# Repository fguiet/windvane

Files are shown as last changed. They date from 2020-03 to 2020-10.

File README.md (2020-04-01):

# Solar powered, waterproof windvane

## Foreword

Following my first project ie a [solar powered waterproof anemoter](https://github.com/fguiet/anemometer), let me introduce you : the solar powered waterproof windvane.
Mostly based on the same form factor, I only had to re-designed the top part with Fusion 360.

## How it works ?

There are eight resistors in the wind vane, and as the magnet rotates, different reed switches will open and close and thus switch their corresponding resistor in and out of the circuit.

Schematic reedwitches and resistors

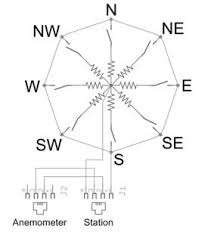
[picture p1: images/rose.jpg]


Implementation reedswitches and resistors

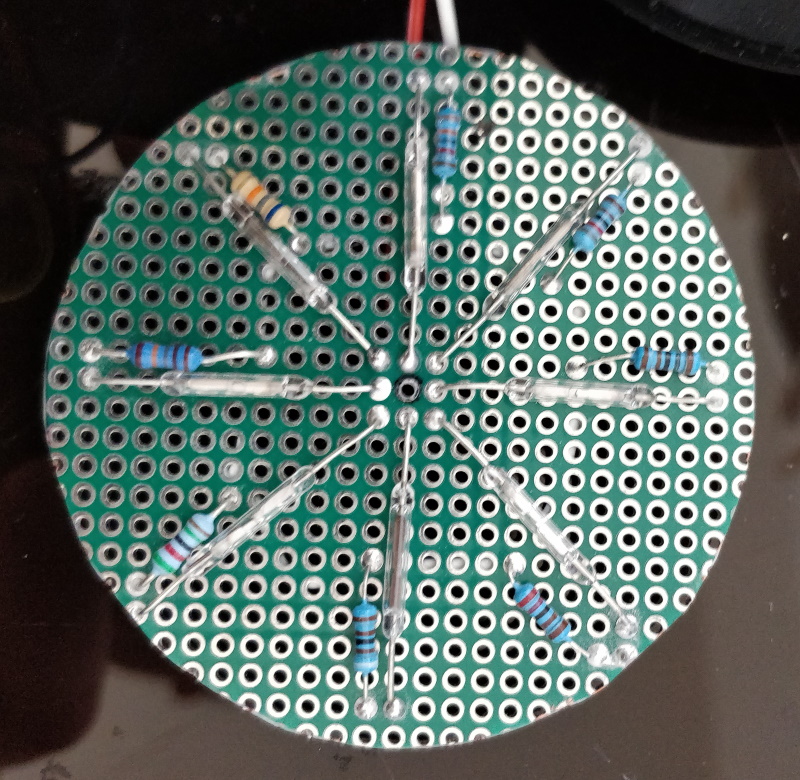
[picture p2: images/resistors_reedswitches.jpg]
Reedswitch


Voltage divider (R1 is 10kOhm is this project and R2 will vary regarding how reed switches are open or close)

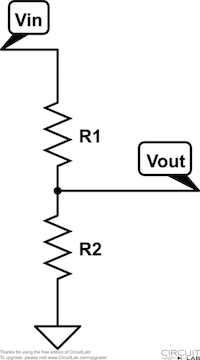
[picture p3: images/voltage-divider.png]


## Specifications

Electronic spare parts needed :

* 3.7v Lithium battery (650 mAh)
* [Lithium battery charger module TP4056](https://www.aliexpress.com/item/32797834680.html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,searchweb201602_,searchweb201603_)
* [ESP32 DevKit)](https://www.aliexpress.com/item/32818515531.html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,searchweb201602_,searchweb201603_)
* Home made voltage divider with 2 resitors 33KOhm and 7.5kOhm
* [Solar panel](https://www.aliexpress.com/item/32327321902.html?spm=a2g0s.9042311.0.0.27424c4dXw694V)
* [XH2.54 connectors](https://www.aliexpress.com/item/32751262161.html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,searchweb201602_,searchweb201603_)
* [30 AWG (0.08mm) silicon wire](https://www.aliexpress.com/item/1000006501735.html?spm=a2g0s.9042311.0.0.27424c4d4oyuHy)
* 3.7v Lithium battery (1200 mAh)
* [Bearing 608ZZ](https://www.aliexpress.com/wholesale?catId=0&initiative_id=SB_20200219052438&SearchText=bearing+608)
* [4 neodymium magnets (8mm)](https://www.aliexpress.com/item/32959402237.html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,searchweb201602_,searchweb201603_)
* Some resistors
* Some nuts and bolts

## Wiring

Quite easy : 

* Wire positive and negative 3.7v battery to ESP32 DevKit (Careful connect to 5v pin, not 3.3v !!), Voltage divider (the one that will measure the battery voltage),  TP4056 
* Wire the voltage divider that will measure the wind direction to 3.3v pin (that way we have a constant voltage)
* GPIO34 to output of voltage divider (measure wind direction)
* GPIO35 to ouput of voltage divider (measure battery voltage)

## 3D Models

All 3D models can be found on my [Thingiverse for free](https://www.thingiverse.com/thing:4252764) or in the model3d folder of this project

I included a mount system that fits on H pole like this one : 

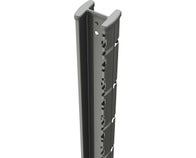
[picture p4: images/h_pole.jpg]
Sweet


If needed, I can provide the 3d model solar panel holder

## In real life

* In place

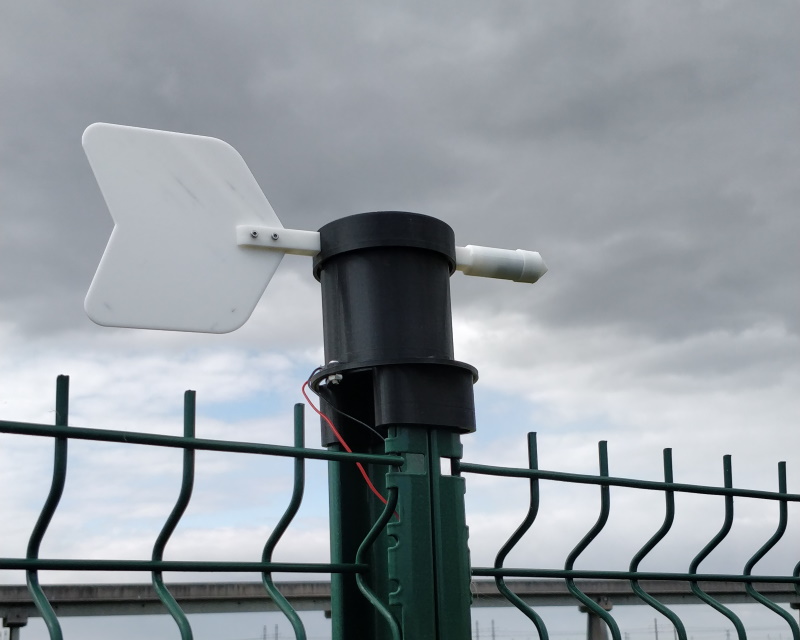
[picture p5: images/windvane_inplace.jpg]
In place


* Inside the beast (we can the custom voltage divider)

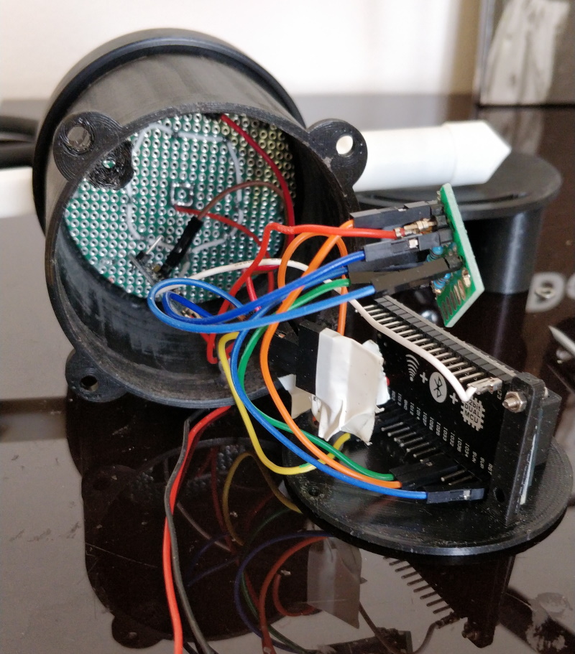
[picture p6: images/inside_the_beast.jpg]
Inside the beast


* Fusion 360 design

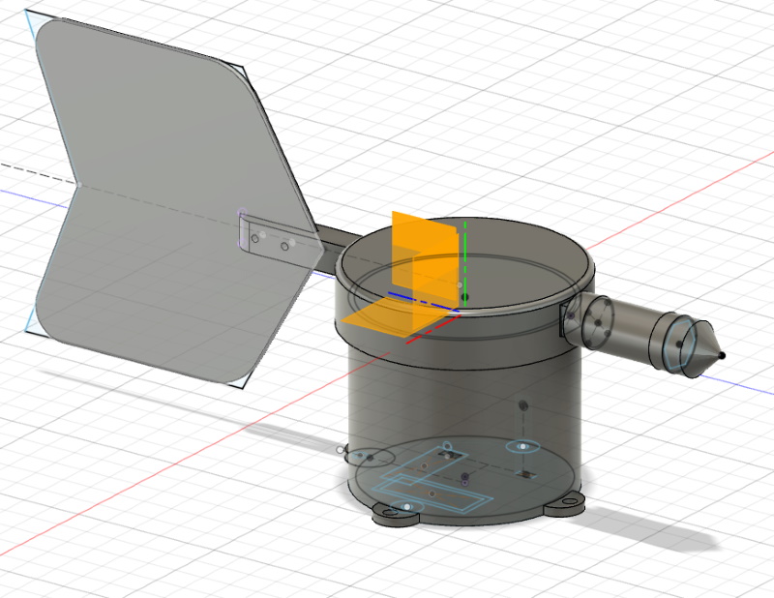
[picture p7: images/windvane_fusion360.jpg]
Fusion 360


* Tampered ESP32 DevKit (I replaced the AMS1117 LDO 1v dropout by HT7333 only 250mA but low dropout)

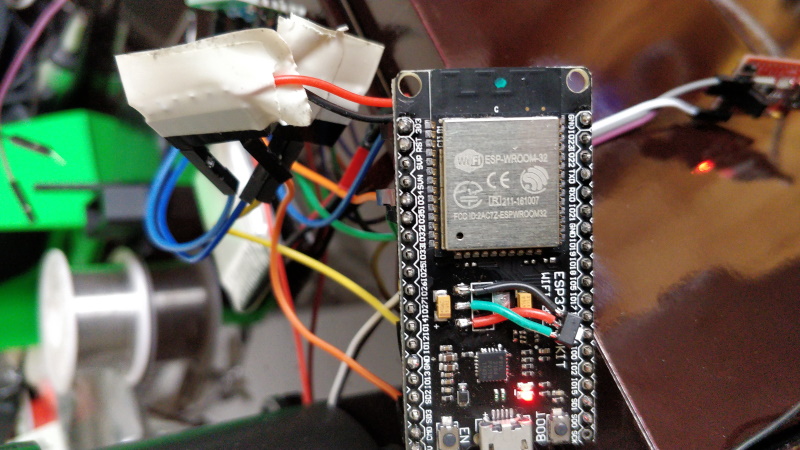
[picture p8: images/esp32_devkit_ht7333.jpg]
Tampered ESP32


* Top view (we can see the bearing)

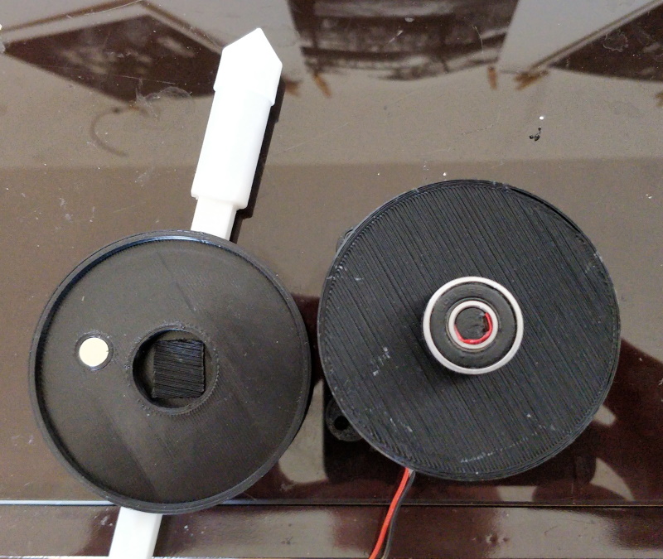
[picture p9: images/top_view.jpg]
Top view


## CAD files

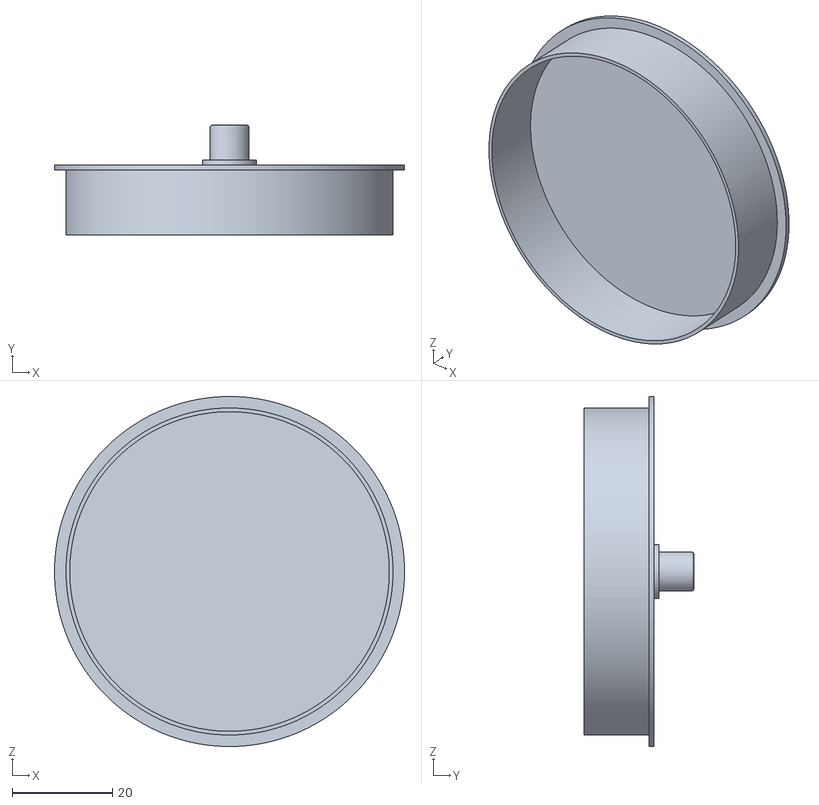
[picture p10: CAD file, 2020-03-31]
model3d/top.stl
70.0 x 22.0 x 70.0

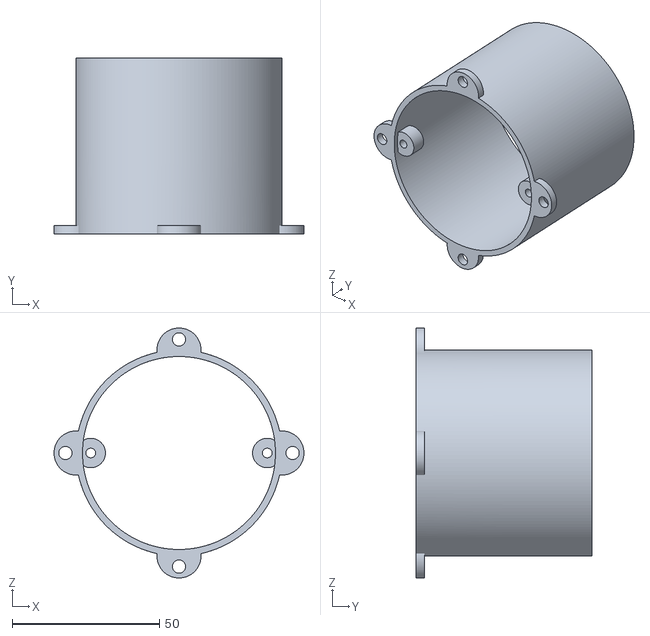
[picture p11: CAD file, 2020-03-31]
model3d/body.stl
85.0 x 60.0 x 85.0

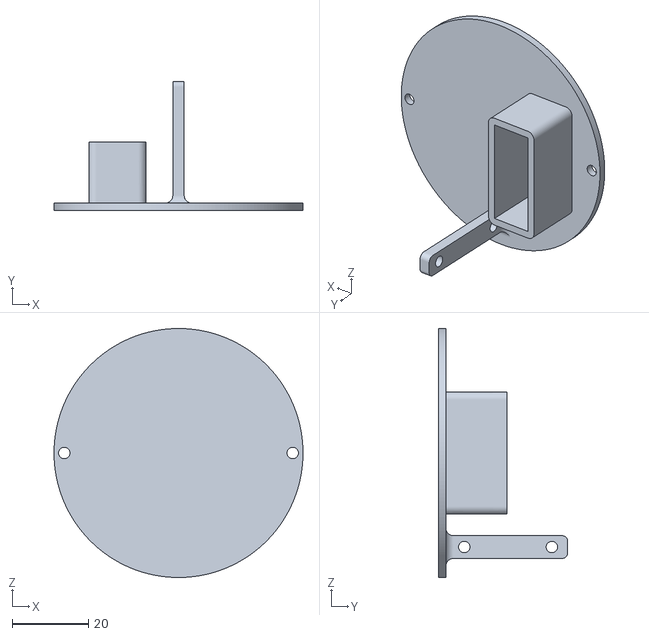
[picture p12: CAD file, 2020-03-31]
model3d/Bottom_ESP32devkit.stl
65.4 x 34.0 x 65.4

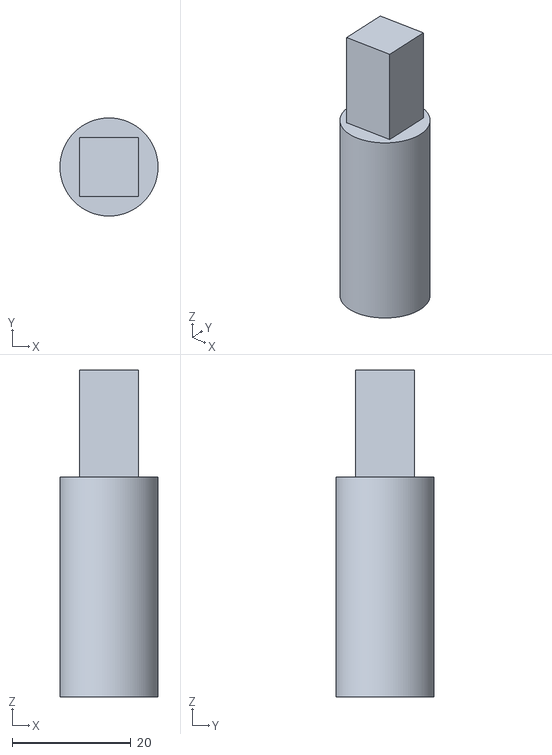
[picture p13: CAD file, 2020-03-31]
model3d/begintail.stl
16.5 x 16.5 x 55.0

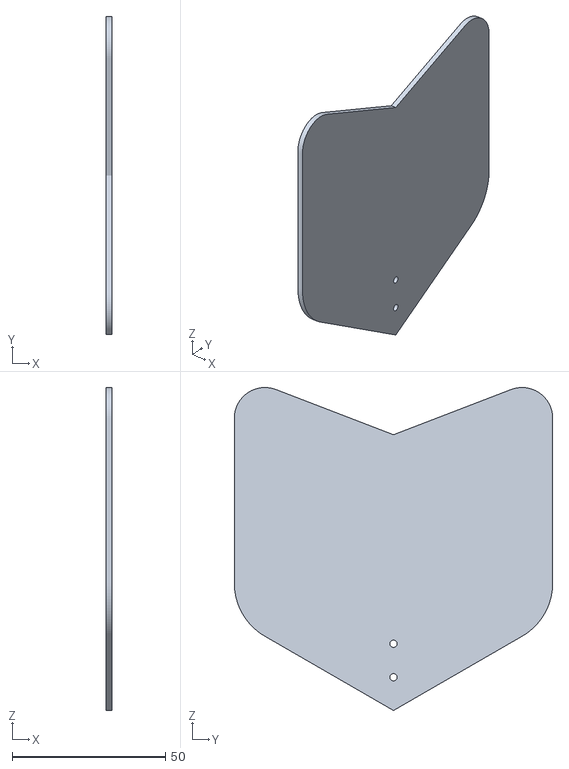
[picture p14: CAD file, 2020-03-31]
model3d/endtail.stl
2.00 x 103.9 x 105.4

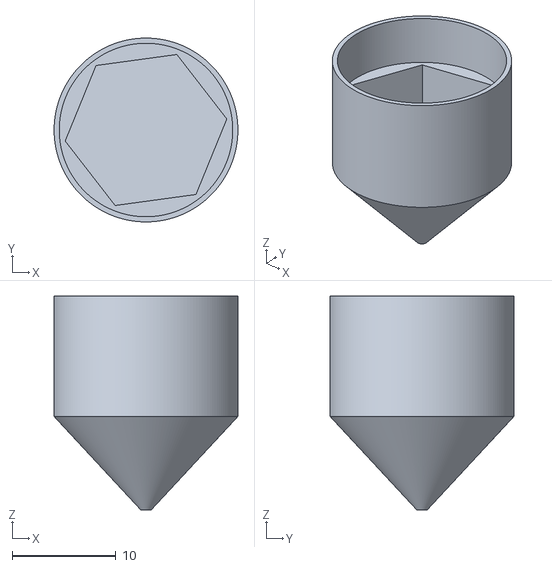
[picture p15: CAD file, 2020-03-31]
model3d/noze.stl
17.7 x 17.7 x 20.6

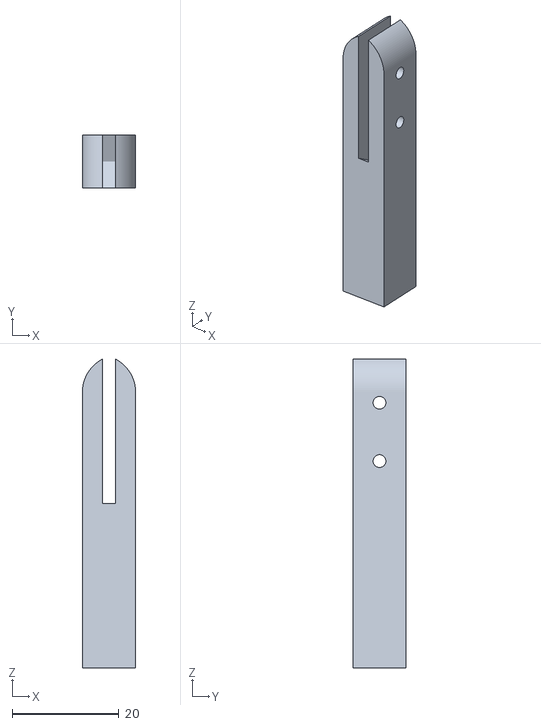
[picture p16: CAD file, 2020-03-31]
model3d/tail.stl
10.0 x 10.0 x 58.0

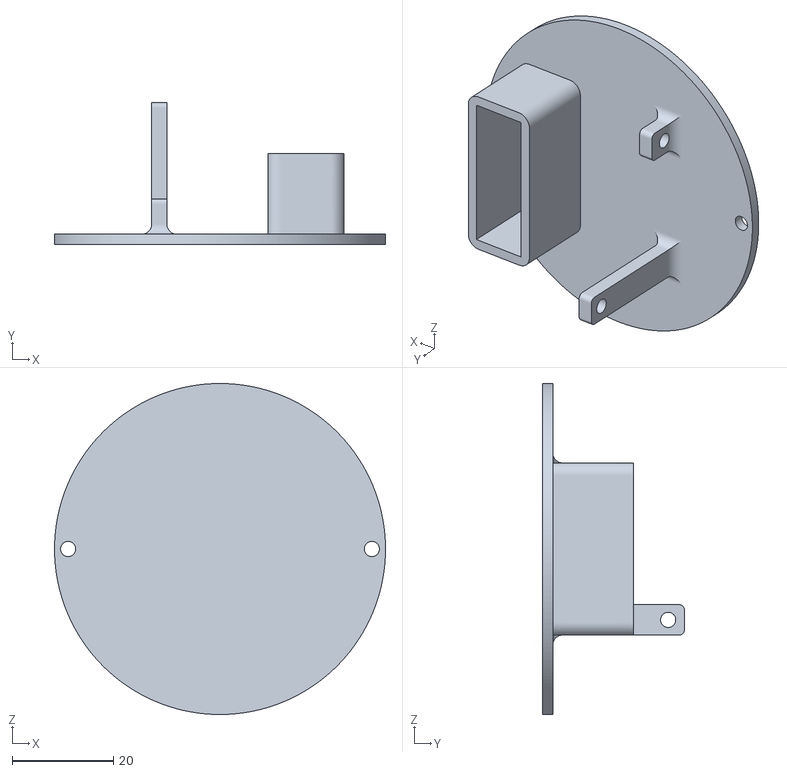
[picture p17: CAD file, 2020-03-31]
model3d/Bottom_WemosD1.stl
65.4 x 28.0 x 65.4

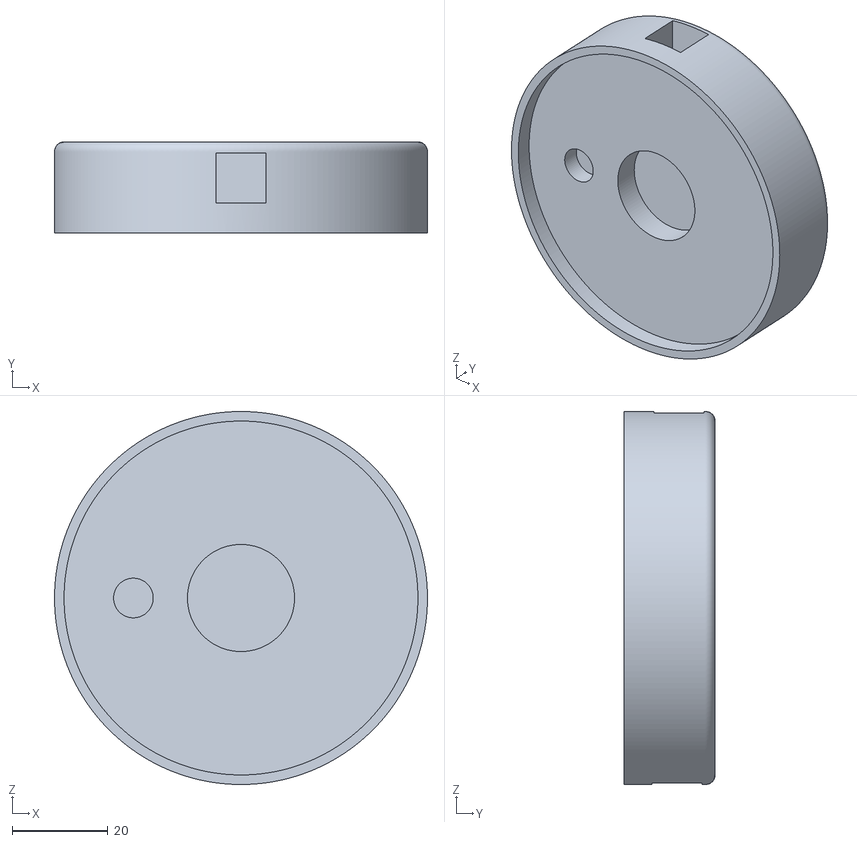
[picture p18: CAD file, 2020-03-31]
model3d/roof.stl
78.0 x 19.1 x 78.0

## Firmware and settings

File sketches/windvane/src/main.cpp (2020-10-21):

/* 
Windvane

   Author :             F. Guiet 
   Creation           : 20200324
   Last modification  : 
  
  Version            : 1.0
  History            : 1.0 - First version
                       1.1 - Replaced AMS117 LDO regulator to HT7333 LDO (1V dropout of AMS117 was too much when powered ESP32 via 5v pin with 3.7v lithium battery) 
                             => the 3.3v pin displayed 2.8v ... when battery was 3.9v :( with HT7333 it's much better...but wareful it can deliver only 250mA max) 
                       1.2 - 2020.04.01 - Read voltage correction. 
                       1.3 - 2020.10.17 - Take "Unknown value into account...otherwise it could drain the battery when reedwitch are ko  
                       1.4 - 2020.10.17 - Switch to PlatformIO, replace ESP32 Dev Kit          
                       
References :   

ESP32 Dev kit : https://randomnerdtutorials.com/getting-started-with-esp32/

Deep sleep mode consumption (ESP32 Devkit) : 7.3mA 
Wake up mode (ESP32 Devkit)                : 63mA

*/
#include <Arduino.h>
#include <ArduinoJson.h>
//Light Mqtt library
#include <PubSubClient.h>
//Wifi library
#include <WiFi.h>

#include "soc/soc.h"           // Disable brownour problems
#include "soc/rtc_cntl_reg.h"  // Disable brownour problems

#define MQTT_SERVER "192.168.1.25"
// WiFi settings
const char* ssid = "DUMBLEDORE";
const char* password = "frederic";

#define MQTT_CLIENT_ID "WindvaneSensor"
#define MAX_RETRY 500

WiFiClient espClient;
PubSubClient client(espClient);

#define DEBUG 0
#define FIRMWARE_VERSION "1.4"

int counter = 0;
int samples = 9;
unsigned long last_millis = 0;
const int get_direction_frequency = 5000;  //10s = 10000
char message_buff[200];

String directions[] = { "South", "South-South-East", "South-East","East-South-East", "East","East-North-East", "North-East","North-North-East","North","North-North-West", "North-West","West-North-West","West","West-South-West","South-West","South-South-West" };


// one hour = 3600 s
// half hour = 1800 s
// quarter hour = 900 s
#define uS_TO_S_FACTOR 1000000ULL  /* Conversion factor for micro seconds to seconds */
#define TIME_TO_SLEEP  900        /* Time ESP32 will go to sleep (in seconds) */

const int WINDIRSENSOR_PIN = 34;
const int BATTERYSENSOR_PIN = 33;
const int LED_PIN = 2;

DynamicJsonDocument doc(500);
JsonObject winddir = doc.to<JsonObject>();

struct Sensor {
    String Name;    
    String SensorId;
    String Mqtt_topic;
};

#define SENSORS_COUNT 1
Sensor sensors[SENSORS_COUNT];

void debug_message(String message, bool doReturnLine) {
  if (DEBUG) {
    if (doReturnLine) {
      //mySerial.println(message);
      Serial.println(message);
    }
    else {
      //mySerial.println(message);
      Serial.print(message);
    }

    //Be sure everything is printed on screen!
    Serial.flush();
  }
}

void disconnectMqtt() {
  debug_message("Disconnecting from mqtt...", true);
  client.disconnect();
}

void disconnectWifi() {
  debug_message("Disconnecting from wifi...", true);
  WiFi.disconnect();
}

boolean connectToMqtt() {

   client.setServer(MQTT_SERVER, 1883); 

  int retry = 0;
  // Loop until we're reconnected
  while (!client.connected() && retry < MAX_RETRY) {
    debug_message("Attempting MQTT connection...", true);
    
    if (client.connect(MQTT_CLIENT_ID)) {
      debug_message("connected to MQTT Broker...", true);
    } else {
      retry++;
      // Wait 5 seconds before retrying
      delay(500);
      //yield();
    }
  }

  if (retry >= MAX_RETRY) {
    debug_message("MQTT connection failed...", true);  
    return false;
  }

  return true;
}

boolean connectToWifi() {
  
  debug_message("Connecting to WiFi...", true);
  
  int retry = 0;

  WiFi.setHostname(MQTT_CLIENT_ID);
  WiFi.begin(ssid, password);

  debug_message("Begin WiFi...", true);

  
  while (WiFi.status() != WL_CONNECTED && retry < MAX_RETRY) {
    retry++;
    delay(500);
    debug_message(".", false);
  }

  if (WiFi.status() == WL_CONNECTED) {  
     debug_message("WiFi connected", true);  
     // Print the IP address
     if (DEBUG) {
      Serial.println(WiFi.localIP());
     }
     
     return true;
  } else {
    debug_message("WiFi connection failed...", true);   
    return false;
  }  
}

void print_wakeup_reason(){
  esp_sleep_wakeup_cause_t wakeup_reason;

  wakeup_reason = esp_sleep_get_wakeup_cause();

  switch(wakeup_reason)
  {
    case ESP_SLEEP_WAKEUP_EXT0 : debug_message("Wakeup caused by external signal using RTC_IO", true); break;
    case ESP_SLEEP_WAKEUP_EXT1 : debug_message("Wakeup caused by external signal using RTC_CNTL", true); break;
    case ESP_SLEEP_WAKEUP_TIMER : debug_message("Wakeup caused by timer", true); break;
    case ESP_SLEEP_WAKEUP_TOUCHPAD : debug_message("Wakeup caused by touchpad", true); break;
    case ESP_SLEEP_WAKEUP_ULP : debug_message("Wakeup caused by ULP program", true); break;
    default : debug_message("Wakeup was not caused by deep sleep", true); break;
  }
}

void InitSensors() {
  
  sensors[0].Name = "Windvane";
  sensors[0].SensorId = "21";
  sensors[0].Mqtt_topic = "guiet/outside/sensor/21";
}

void setup() {
  // put your setup code here, to run once:
  pinMode(WINDIRSENSOR_PIN, INPUT);
  pinMode(BATTERYSENSOR_PIN, INPUT);
  pinMode(LED_PIN, OUTPUT);

  //Turn off LED (save some mA)
  digitalWrite(LED_PIN, HIGH);
  
   // Initialize Serial Port
  if (DEBUG) {
    Serial.begin(9600);
    print_wakeup_reason();
  }

  InitSensors();

  last_millis = millis();

  uint32_t brown_reg_temp = READ_PERI_REG(RTC_CNTL_BROWN_OUT_REG); //save WatchDog register
  WRITE_PERI_REG(RTC_CNTL_BROWN_OUT_REG, 0); //disable brownout detector

  debug_message("Setup completed, starting...",true); 
}

float ReadVoltage() {

  //AnalogRead = 870 pour 4.2v

  //R1 = 33kOhm
  //R2 = 7.5kOhm

  float sensorValue = 0.0f;  
  
  delay(100); //Tempo so analog reading will be correct!
  sensorValue = analogRead(BATTERYSENSOR_PIN);
    
  debug_message("Analog Reading : " + String(sensorValue,2), true);

  return (sensorValue * 4.20) / 870;

}

float getDegree(String direction) {
  
  if (direction=="South") {
    return 180;
  }

  if (direction=="South-South-East") {
    return 157.5;
  }

  if (direction=="South-East") {
    return 135;
  }

  if (direction=="East-South-East") {
    return 112.5;
  }

  if (direction=="East") {
    return 90;
  }

  if (direction=="East-North-East") {
    return 67.5;
  }

  if (direction=="North-East") {
    return 45;
  }

  if (direction=="North-North-East") {
    return 22.5;
  }

  if (direction=="North") {
    return 0;
  }

  if (direction=="North-North-West") {
    return 337.5;
  }

  if (direction=="North-West") {
    return 315;
  }

  if (direction=="West-North-West") {
    return 292.5;
  }

  if (direction=="West") {
    return 270;
  }

  if (direction=="West-South-West") {
    return 247.5;
  }

  if (direction=="South-West") {
    return 225;
  }

  if (direction=="South-South-West") {
    return 202.5;
  }

  return -1;
}

String ConvertToJSon(String battery, String dirWin) {
    //Create JSon object
    DynamicJsonDocument  jsonBuffer(200);
    JsonObject root = jsonBuffer.to<JsonObject>();
    
    root["id"] = sensors[0].SensorId;
    root["name"] = sensors[0].Name;
    root["firmware"]  = FIRMWARE_VERSION;
    root["battery"] = battery;    
    root["winddirection"] = dirWin;
    root["degree"] = String(getDegree(dirWin),1);
    
    String result;    
    serializeJson(root, result);

    return result;
}

void SendResult() {

   if (WiFi.status() != WL_CONNECTED) {
    if (!connectToWifi())
      return;
  }  

  if (!client.connected()) {
    if (!connectToMqtt()) {
      return;
    }
  }

  int winner = 0;
  String dirWin = "Unknown";
  for (int i=0;i<16;i++) {
    if (winddir.containsKey(directions[i])) {
      if (winddir[directions[i]].as<int>() > winner) {
        dirWin=directions[i];
        winner=winddir[directions[i]].as<int>();
      }
    }    
  }

  debug_message("Winner is : " + dirWin, true);

  float vin = ReadVoltage();
  String mess = ConvertToJSon(String(vin,2), dirWin);
  debug_message("JSON Sensor : " + mess + ", topic : " +sensors[0].Mqtt_topic, true);
  mess.toCharArray(message_buff, mess.length()+1);
    
  client.publish(sensors[0].Mqtt_topic.c_str(),message_buff);

  disconnectMqtt();
  delay(100);
  disconnectWifi();
  delay(100);
}

String getWindDirection(float voltage) {

  if (voltage >= 565 and voltage <= 660) {
    return directions[0]; //South
  }

  if (voltage >= 500 and voltage <= 560) {
    return directions[1] ; //South-South-East    
  }

  if (voltage >= 2500 and voltage <= 2600) {
    return directions[2] ; //"South-East"    
  }
  
  /*if (voltage >= 2300 and voltage <= 2380) {
    return directions[3];  //"East-South-East";    
  }*/

  if (voltage >= 2300 and voltage <= 2380) {
    return directions[4]; //"East";    
  }

  if (voltage >= 3650 and voltage <= 3750) {
    return directions[5]; //"East-North-East";    
  }

  if (voltage >= 3380 and voltage <= 3450) {
    return directions[6]; //"North-East";
  }

  if (voltage >= 3800 and voltage <= 3910) {
    return directions[7]; //"North-North-East";
  }

  if (voltage >= 4050 and voltage <= 4096) {
    return directions[8]; //"North";
  }

  if (voltage >= 2970 and voltage <= 3050) {
    return directions[9]; //"North-North-West";
  }

  if (voltage >= 3090 and voltage <= 3150) {
    return directions[10]; //"North-West";
  }

  if (voltage >= 2170 and voltage <= 2220) {
    return directions[11]; //"West-North-West";
  }

  if (voltage >= 2620 and voltage <= 2700) {
    return directions[12]; //"West";
  }

  if (voltage >= 980 and voltage <= 1050) {
    return directions[13]; //"West-South-West";
  }

  if (voltage >= 1180 and voltage <= 1250) {
    return directions[14]; //"South-West";
  }
  
  if (voltage >= 320 and voltage <= 420) {
    return directions[15]; //"South-South-West";
  }

  return "Unknown";
}

void loop() {

  /*ReadVoltage();

  delay(200);

  return;*/
  
  
  //Get Wind direction every get_direction_frequency ms
  if (millis() - last_millis >= get_direction_frequency ) { 

    debug_message("Reading number : " + String(counter), true);  

    float voltage = analogRead(WINDIRSENSOR_PIN);  
    debug_message("Analog Reading : " + String(voltage,2), true);  
    String windDirection = getWindDirection(voltage);
    debug_message("Wind direction : " + windDirection, true);  
    
    //if (windDirection != "Unknown" ) {
      counter++;

      if (winddir.containsKey(windDirection)) {
        winddir[windDirection]=winddir[windDirection].as<int>()+1;
      }
      else {
        winddir[windDirection]=1;
      }
    //}

    last_millis = millis();
  }

  //For testing purpose
  //return;

  if (counter >= samples) {
    SendResult();
    debug_message("Going to sleep...na night", true);

    esp_sleep_enable_timer_wakeup(TIME_TO_SLEEP * uS_TO_S_FACTOR);
    debug_message("Setup ESP32 to sleep for every " + String(TIME_TO_SLEEP) + " Seconds", true);
    
    esp_deep_sleep_start();
  }
}

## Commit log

2020-03-29 Replace AMS1117 LDO by HT7333
    [windvane.ino]
2020-03-31 add 3d models
    [Bottom_ESP32devkit.stl, Bottom_WemosD1.stl, begintail.stl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]
2020-10-17 Update resistor values
2020-10-21 adjust voltage
